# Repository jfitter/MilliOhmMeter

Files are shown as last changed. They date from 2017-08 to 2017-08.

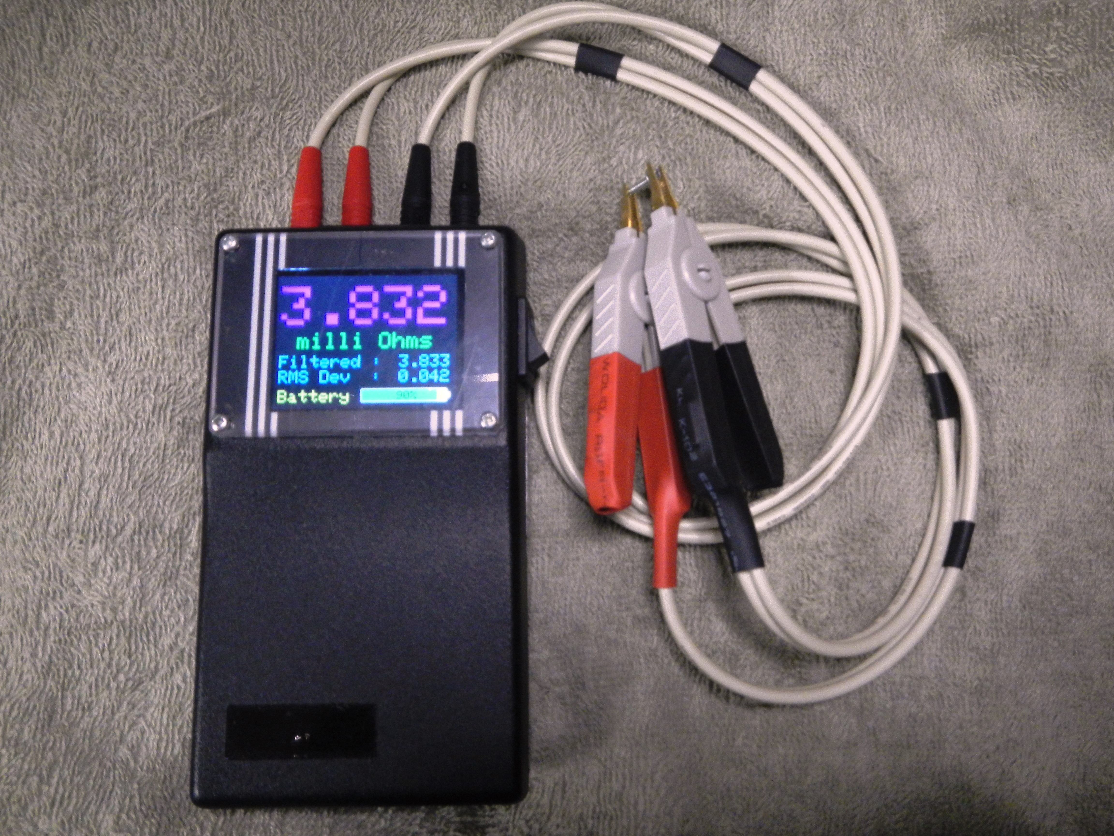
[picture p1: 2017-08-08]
Pictures/measure.jpg

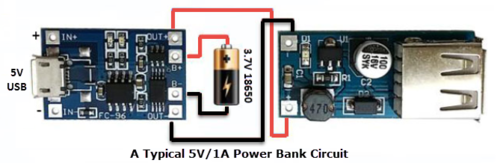
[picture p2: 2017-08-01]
Hardware/Micro-LI-Bat-Chg-Module-Connections.png

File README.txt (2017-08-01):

****************************************************************************************************
* This is the firmware for the MilliOhm Meter (described herein)                                   *
****************************************************************************************************

Firmware for MilliOhm Meter using the following hardware;
    Scullcom milliohm meter circuit
    Arduino Pro Mini
    ADS1115 breakout board
    2.2" 240x320 SPI TFT LCD with ILI9341 driver
    Micro USB single LiIon battery charger module
    LiIon single cell boost converter module
    18650 2500mAh LiIon cyclindrical cell

Hardware setup.
Using an Arduino Pro Mini @ 16MHz / 5V.

Description & Function              Arduino Arduino
======================              Pin #   Pin Name
                                    ======= ========
ADS1115 16b A/D Converter I2C
    SDA   (Serial Data)             A4      ADC4 (SDA)
    SCL   (Serial Clock)            A5      ADC5 (SCL)

2.2" TFT RGB 240x320 Display (ILI9341)
    MISO  (Serial Out)              12      PB4 (MISO) (Serial In)
    MOSI  (Serial In)               11      PB3 (MOSI) (Serial Out)
    SCK   (Serial Clock)            13      PB5 (SCK)  (Serial Clock)
    LED   (Backlight)               2       PD2
    DC/RS (SD Card Select)          3       PD3
    RST   (Reset)                   4       PD4
    CS    (LCD Select)              5       PD5

ADS1115 Module Analog Inputs
    0,1   Differential              MilliOhm meter output
    2     Single ended              LiIon battery voltage

Check that the archive contains the following files;

MilliOhmMeter.ino       Arduino C++ source
MilliOhmMeter.h         C++ header
MilliOhmMeter.chm       The HTML documentation
MilliOhmMeter.vcxproj   Visual Studio project file
Filter.h                Exponential Filter source
printf.h                Formatted print source
README.txt              This file
Doxyfile                Doxygen documentation configuration

MilliOhmMeter.chm contains the documentation for the firmware.

Written by John Fitter, Eagle Air Australia Pty. Ltd.
BSD license. All text above must be included in any redistribution

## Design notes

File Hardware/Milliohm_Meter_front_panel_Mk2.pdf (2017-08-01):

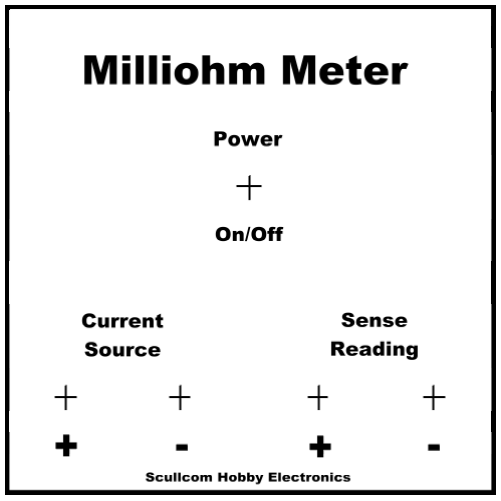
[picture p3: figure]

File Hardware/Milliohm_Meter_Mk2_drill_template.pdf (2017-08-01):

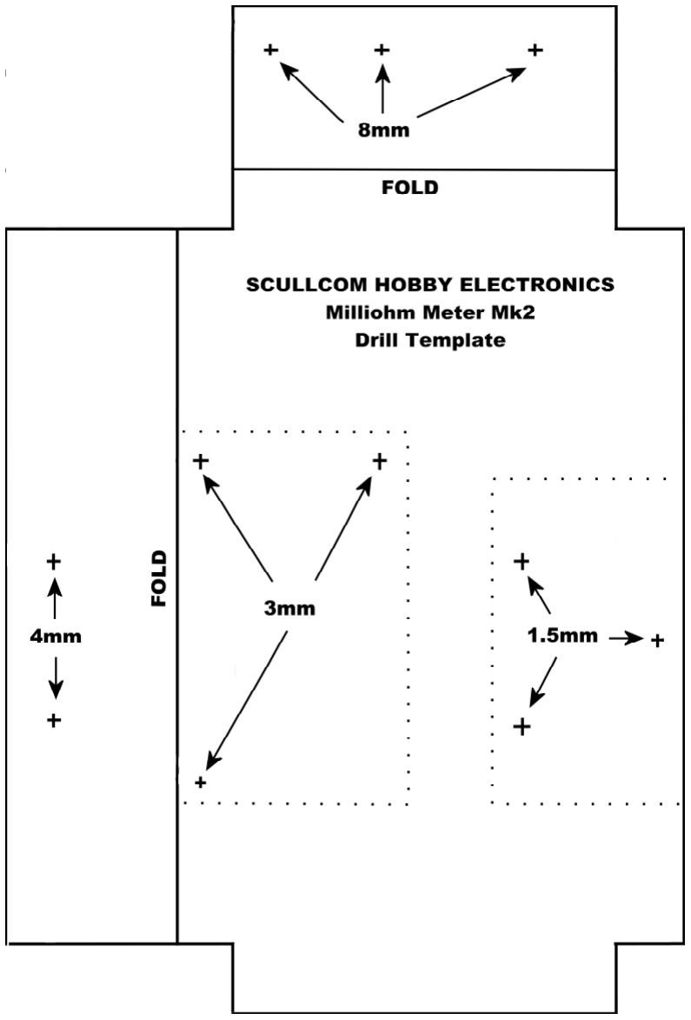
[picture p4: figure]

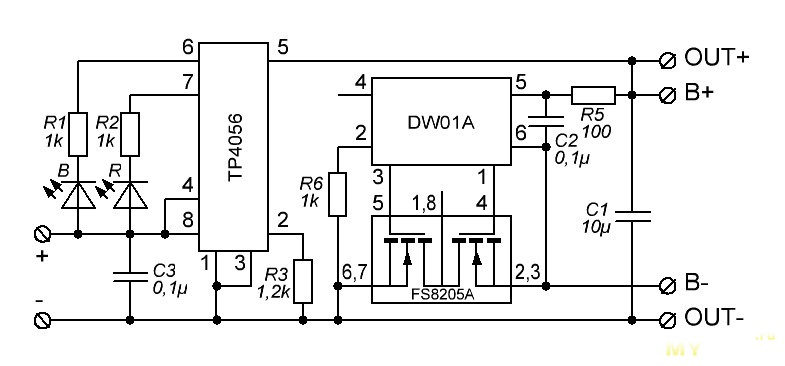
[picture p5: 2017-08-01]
Hardware/Micro-LI-Bat-Chg-Module-Schematic.jpg

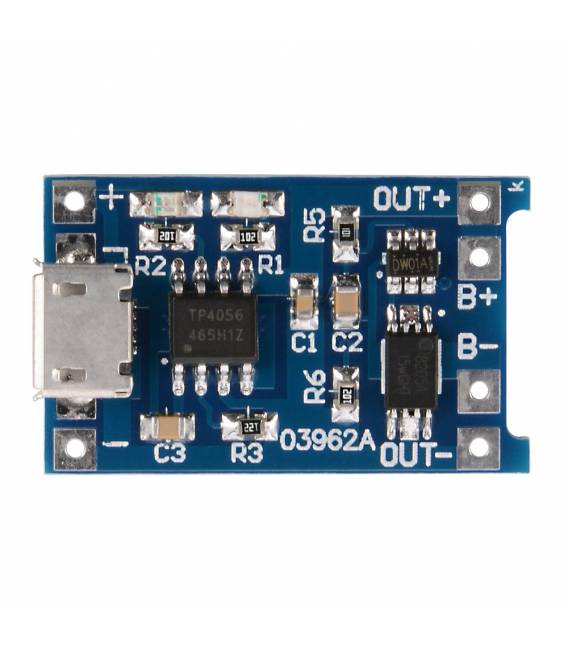
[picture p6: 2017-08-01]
Hardware/Micro-LI-Bat-Chg-Module-Image.jpg

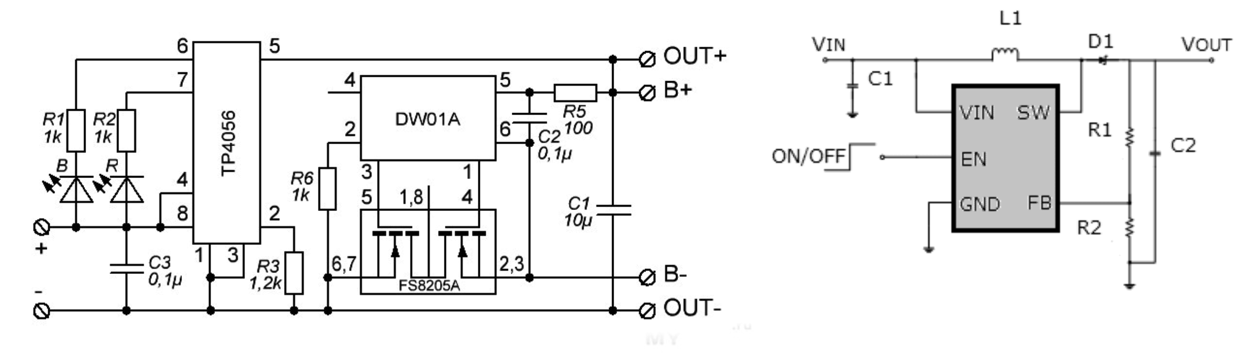
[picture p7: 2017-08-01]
Hardware/Power_Charging.jpg

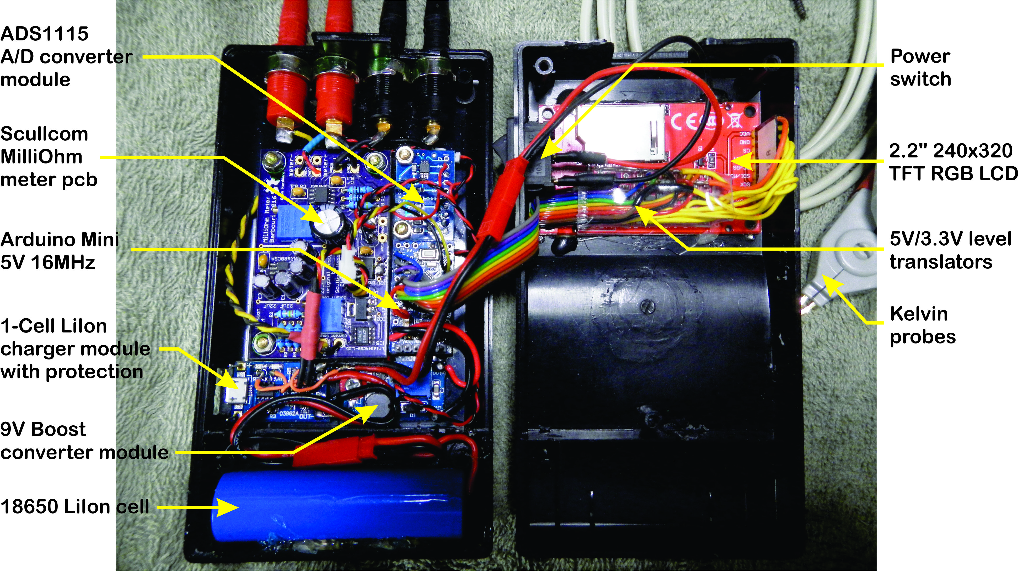
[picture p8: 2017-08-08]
Pictures/inside.jpg

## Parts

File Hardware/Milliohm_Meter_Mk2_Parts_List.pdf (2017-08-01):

SCULLCOM HOBBY ELECTRONICS - MILLIVOLT METER Mk2 PARTS LIST

PCB is available from OSH Park. A PCB (using surface mount components) designed by one of my subscribers “pbreviceps” (Greg Christenson). Greg has taken my design and produced a very high quality PCB (double sided) and made it freely available to purchase from OSH Park (3 blank PCB’s are supplied at a cost of US$19.5 plus shipping costs). Direct link: https://oshpark.com/shared_projects/UWvehNO2

1 x LM2940IMP-5.0 - SOT-223 (Farnell Order Code 1469076) 1 x LT3092EST#PBF - SOT223 (Farnell Order Code 2295469) 1 x LT1634BCS8-1.25#PBF NSOIC-8 (Farnell Order Code 1273451) 1 x MAX680CSA+ NSOIC-8 (Farnell Order Code 9725717) 1 x INA106U –SOIC (Farnell Order Code 1212395) 4 x 56.2 Ω 250 mW, ± 0.1% ±15ppm/°C (Farnell Order Code 9503277 or 1751304) 1 x 63.4 Ω 250 mW, ± 0.1% ±15ppm/°C (Farnell Order Code 1083123) 1 x 10 Ω 250 mW, ± 0.1% ±15ppm/°C (Farnell Order Code 1083036) 1 x 100 Ω 250 mW, ± 0.1% ±15ppm/°C (Farnell Order Code 9499865 or 1083143) 1 x 499 KΩ 250 mW, ± 0.1% ±15ppm/°C (Farnell Order Code 1083547) 1 x 220 μF 35v electrolytic (Farnell Order Code 1144628) or similar 4 x 22 μF 25v electrolytic (Farnell Order Code 2079085) or similar 5 x 0.1 μF ceramic (Farnell Order Code 2529480) or similar 1 x 100 Ω preset (BOURNS 3296P-1-101LF TRIMMER, 25 TURN 100R (Farnell Order Code 9353020)

1 x 100 KΩ preset (BOURNS 3296P-1-104LF TRIMMER, POT, 100K, 10%, 25TURN, (Farnell Order Code 9353054)

1 x 4 ½ Digit High Precision +/- 2V 0-1.9999V Red LED Digital Panel Meter.
From seller yourcartmax on eBay. Direct link below: http://www.ebay.co.uk/itm/261284812938?_trksid=p2057872.m2749.l2649&ssPageName=STRK%3AMEBID X%3AIT
or alternative from eBay seller coldfusionx, direct link: http://www.ebay.com/itm/350261421976

1 x Black textured ABS enclosure with sloping panel. 150mm length, 95mm width, height slopes from 33.2 to 49.5mm. From www.rapidonline.com (Order Code: 30-3606). Direct link below: https://www.rapidonline.com/rapid-g1168b-150x95x50-black-case-30-3606

1 x PP3 9V Battery Holder Clip Connector. From seller utronix_ltd on eBay. http://www.ebay.co.uk/itm/PP3-9V-BATTERY-HOLDER-CLIP-CONNECTOR-IDEAL-FOR-GUITAR-EFFECTS-PEDAL-/262341198335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

High quality Alligator Kelvin Test gold plated clip 2 Colors Red + Black. From seller louisliu2009 on eBay. Direct link below:
http://www.ebay.co.uk/itm/4pcs-High-quality-Alligator-Kelvin-Test-gold-plated-clip-2-Colors-Red-Black-/180779978390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

### 2 x 4mm Insulated Test Socket Red (Rapid order code 17-2677) or similar 2 x 4mm Insulated Test Socket Black (Rapid order code 17-2674) or similar 1 x 4mm Insulated Test Socket Yellow (Rapid order code 17-2679) or similar 1 x 4mm Insulated Test Socket Green (Rapid order code 17-2676) or similar

The 4mm sockets available from Rapid, direct link below: or similar https://www.rapidonline.com/4mm-insulated-test-socket-83057

### 1 x On/Off switch either toggle or push button

### 1 x 2.1mm pin diameter DC power socket (Rapid order code 50-3276) or similar

https://www.rapidonline.com/cliff-electronic-fc681445-dc-socket-5-5-x-2-1mm-model-scd-026-50-3276

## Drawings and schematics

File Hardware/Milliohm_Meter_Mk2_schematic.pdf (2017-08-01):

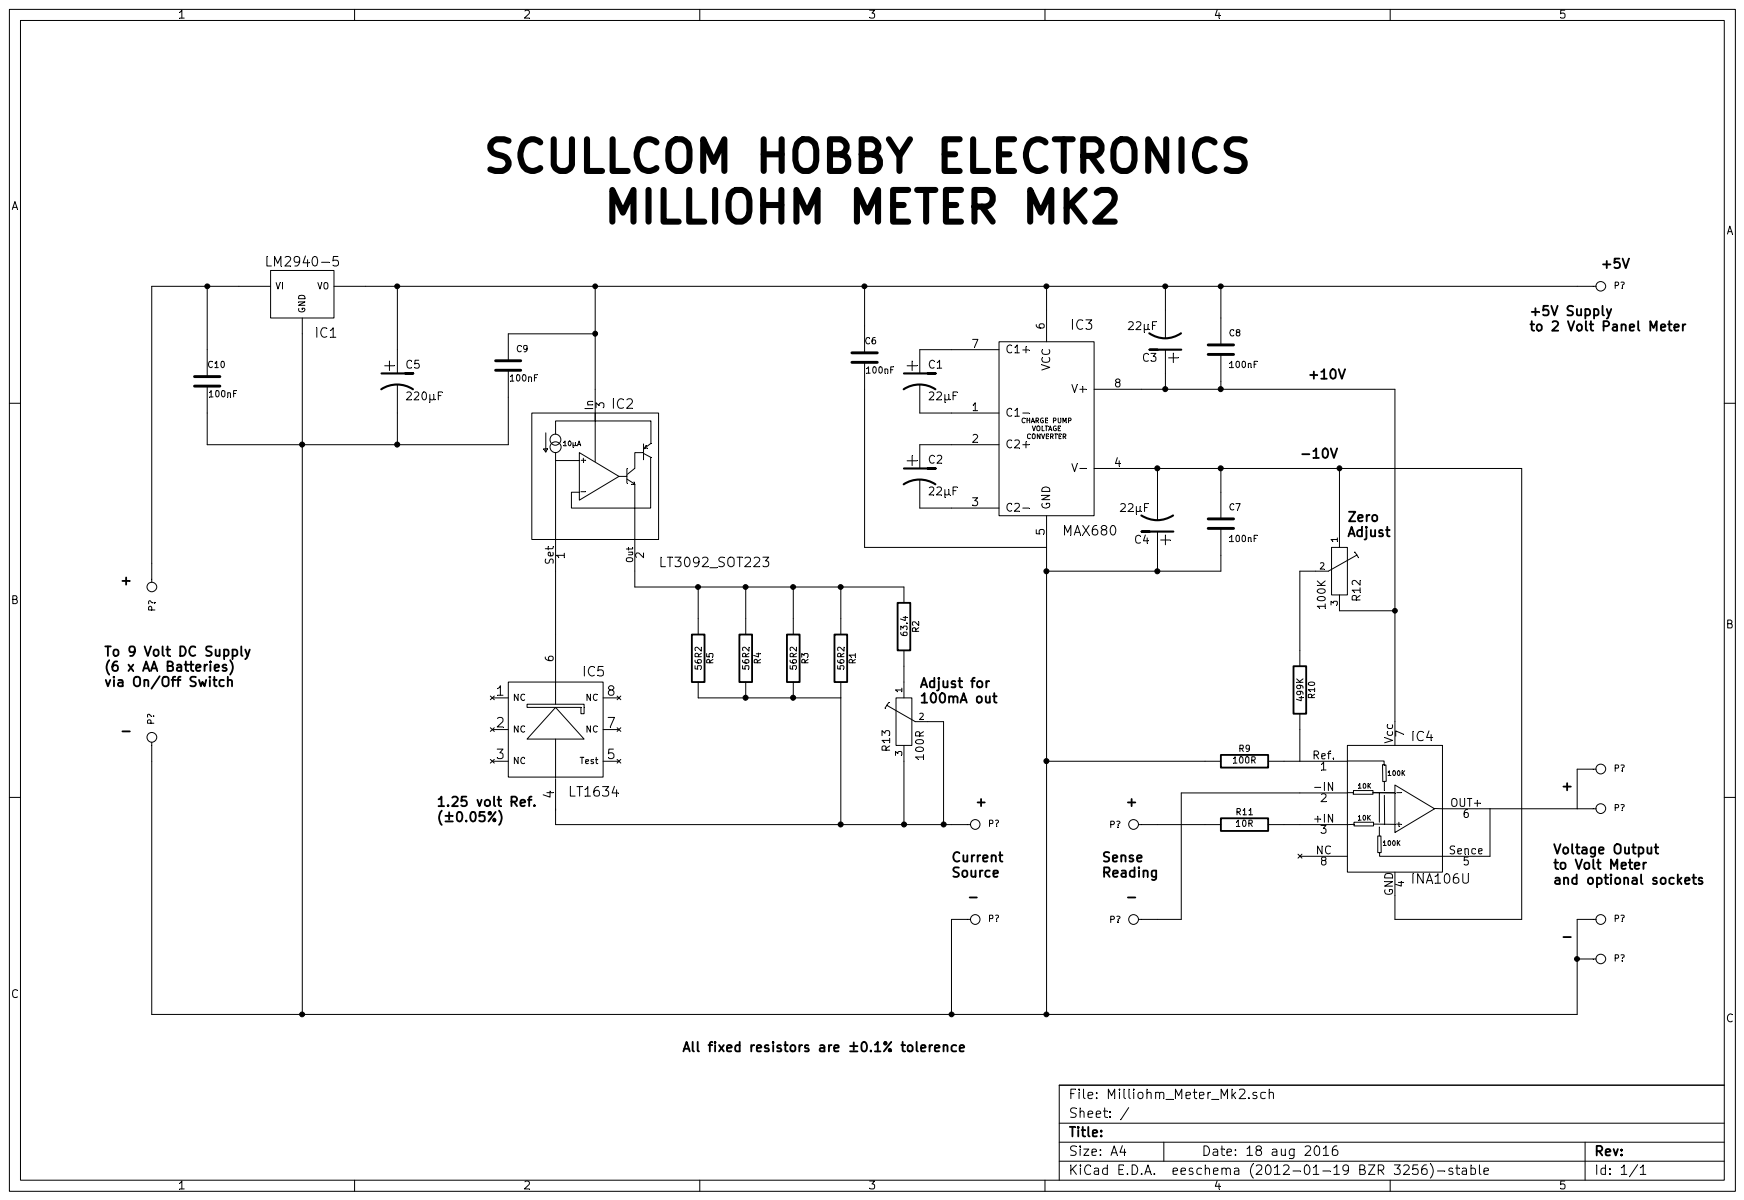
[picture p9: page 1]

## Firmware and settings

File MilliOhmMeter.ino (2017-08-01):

#define _MILLIOHMMETER_C
/***********************************************************************************************//**
 *  \par        MilliOhmMeter Control Program - Source File.
 *
 *  \par        Details
 *              Firmware for MilliOhm Meter using the following hardware;
 *  \li             Scullcom milliohm meter circuit
 *  \li             Arduino Pro Mini
 *  \li             ADS1115 breakout board
 *  \li             2.2" 240x320 SPI TFT LCD with ILI9341 driver
 *  \li             Micro USB single LiIon battery charger module
 *  \li             LiIon single cell boost converter module
 *  \li             18650 2500mAh LiIon cyclindrical cell
 *
 *  \file       MILLIOHMMETER.INO
 *  \author     J. F. Fitter <jfitter@eagleairaust.com.au>
 *  \version    1.0
 *  \date       July 2017
 *  \copyright  Copyright (c) 2017 John Fitter.  All right reserved.
 *
 *  \par        Changelog
 *              23jul2017  Initial release
 *
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
 *  \par
 *  \par        Hardware setup.
 *              Using an Arduino Pro Mini @ 16MHz / 5V.
 *  \verbatim
    Description & Function                     Arduino    Arduino
    ======================                     Pin #      Pin Name
                                               =======    ========
    ADS1115 16b A/D Converter I2C
        SDA   (Serial Data)                    A4         ADC4 (SDA)
        SCL   (Serial Clock)                   A5         ADC5 (SCL)

    2.2" TFT RGB 240x320 Display (ILI9341)
        MISO  (Serial Out)                     12         PB4 (MISO) (Serial In)
        MOSI  (Serial In)                      11         PB3 (MOSI) (Serial Out)
        SCK   (Serial Clock)                   13         PB5 (SCK)  (Serial Clock)
        LED   (Backlight)                      2          PD2
        DC/RS (SD Card Select)                 3          PD3
        RST   (Reset)                          4          PD4
        CS    (LCD Select)                     5          PD5

    ADS1115 Analog Inputs
        0,1   Differential                     MilliOhm meter output
        2     Single ended                     LiIon battery voltage
    \endverbatim
 *
 *//***********************************************************************************************/

#include <avr/pgmspace.h>
#include <Arduino.h>
#include <Wire.h>
#include <SPI.h>
#include <gfxfont.h>
#include <Adafruit_GFX.h>
#include <Adafruit_ILI9341.h>
#include <Adafruit_ADS1015.h>
#include <TimerUp.h>
#include "Filter.h"
#include "printf.h"

#include "MilliOhmMeter.h"

/**
 *  \brief    Program setup.
 *  \remarks  Performed once only at powerup.
 */
void setup() {

    #ifdef _DEBUG_
    startDebug();                                   // Start the debug output.
    #endif // _DEBUG_

    printf_begin();                                 // Start the printf formatter.
    Wire.begin();                                   // Start the serial bus.
    initBattery();                                  // Initialize battery monitoring hardware.
    initAds1115();                                  // Initialize ADS1115.
    initLcd();                                      // Initialize the LCD hardware.
}

/**
 *  \brief    Main program loop.
 *  \remarks  The main loop is merely a scheduler relying on the rollover of several timers to
 *            initiate functions.
 */
void loop() {
    if (procTimer[0].rollOver()) getResistance();
    if (procTimer[1].rollOver()) updateDisplay();
    if (procTimer[2].rollOver()) getBattVolts(); 
}

/**
 *  \brief                   Convert a double value to a formatted string.
 *  \remarks                 Unlike dtostrf() this procedure returns a string of only the specified
 *                           length, leading edge padded with spaces or truncated.
 *  \param [in] double val   Value to be converted.
 *  \param [in] uint8_t len  Length of the string to return.
 *  \param [in] uint8_t prec Precision (ie. number of decimals).
 *  \param [in] char *buf    String buffer to receive the result.
 *  \return     char*        Pointer to the formatted string buffer.
 */
char* dToStringFmt(double val, uint8_t len, uint8_t prec, char *buf) {
    uint8_t n = strlen(dtostrf(val, len, prec, buf));
    return &buf[n-len];
}

/**
 *  \brief    Update the values displayed on the LCD.
 *  \remarks  This procedure writes all of the variable data to the LCD. It performs
 *            Implement a simple linear recursive exponential filter. This is
 *            scaling of the value and selection of the appropriate units.
 */
void updateDisplay() {

    char buf[31];
    uint8_t dec = 0;
    double mul = 1000000.0;

    // If the resistance is over 5 then that is an overrange condition. Just say so and do nothing
    // else. This ensures that previous hard filtered values are held.
    if(resSFilter.Current() > 5.0) {
        writeLcdText("-----", LCD_XCENTER, LCD_YRES, LCD_RES_FONT_SIZE, 
            LCD_TXT_CENTER, LCD_RES_COLOR);
        writeLcdText("Over Range", LCD_XCENTER, LCD_YUNITS, LCD_UNITS_FONT_SIZE, 
            LCD_TXT_CENTER, LCD_UNITS_COLOR);
    } else {

        // Choose to display microOhms/milliOhms/Ohms, select a multiplier for the displayed value,
        // select decimal places, then write the units to the units line on the LCD.
        if(resSFilter.Current() < 0.001) {
            writeLcdText("micro Ohms", LCD_XCENTER, LCD_YUNITS, LCD_UNITS_FONT_SIZE, 
                LCD_TXT_CENTER, LCD_UNITS_COLOR);
        } else if(resSFilter.Current() < 1.0) {
            dec = resSFilter.Current() < 0.01 ? 3 : resSFilter.Current() < 0.1 ? 2 : 1; 
            mul = 1000.0;
            writeLcdText("milli Ohms", LCD_XCENTER, LCD_YUNITS, LCD_UNITS_FONT_SIZE, 
                LCD_TXT_CENTER, LCD_UNITS_COLOR);
        } else {
            dec = 3;
            mul = 1.0;
            writeLcdText("   Ohms   ", LCD_XCENTER, LCD_YUNITS, LCD_UNITS_FONT_SIZE, 
                LCD_TXT_CENTER, LCD_UNITS_COLOR);
        }
        // Write the soft filtered resistance value.
        writeLcdText(dToStringFmt(resSFilter.Current()*mul, 5, dec, buf), LCD_XCENTER, LCD_YRES, 
            LCD_RES_FONT_SIZE, LCD_TXT_CENTER, LCD_RES_COLOR);

        // Write the hard filtered resistance value and the square root of the summ of squares of 
        // the filtered value deviations. The RMS deviation is tested to be less than 10% of the 
        // filtered value. If not then neither the deviation nor the hard filtered values are 
        // displayed at all.
        if (sqrt(devFilter.Current()) > resHFilter.Current() / 10.0) {
            writeLcdText("-----", LCD_RIGHT, LCD_YLINE3, LCD_DATA_FONT_SIZE, 
                LCD_TXT_RIGHT, LCD_DATA_COLOR);
            writeLcdText("-----", LCD_RIGHT, LCD_YLINE4, LCD_DATA_FONT_SIZE, 
                LCD_TXT_RIGHT, LCD_DATA_COLOR);
        } else {
            writeLcdText(dToStringFmt(resHFilter.Current()*mul, 5, dec, buf), LCD_RIGHT,
                LCD_YLINE3, LCD_DATA_FONT_SIZE, LCD_TXT_RIGHT, LCD_DATA_COLOR);
            writeLcdText(dToStringFmt(sqrt(devFilter.Current())*mul, 5, dec, buf), LCD_RIGHT, 
                LCD_YLINE4, LCD_DATA_FONT_SIZE, LCD_TXT_RIGHT, LCD_DATA_COLOR);
        }
        // Just write the fixed text fields (in case they are corrupted for some reason).
        writeLcdText("Filtered :", LCD_LEFT, LCD_YLINE3, LCD_DATA_FONT_SIZE, LCD_TXT_LEFT, 
            LCD_DATA_COLOR);
        writeLcdText("RMS Dev  :", LCD_LEFT, LCD_YLINE4, LCD_DATA_FONT_SIZE, LCD_TXT_LEFT, 
            LCD_DATA_COLOR);
    }
    #ifdef _DEBUG_
    Serial.print(F("Gain: "));
    switch (gn) {
        case GAIN_SIXTEEN   : Serial.print(F("16 ")); break;
        case GAIN_EIGHT     : Serial.print(F("8  ")); break;
        case GAIN_FOUR      : Serial.print(F("4  ")); break; 
        case GAIN_TWO       : Serial.print(F("2  ")); break;   
        case GAIN_ONE       : Serial.print(F("1  ")); break;    
        default             : Serial.print(F("2/3"));
    }
    sprintf_P(buf, PSTR(" Raw: %5d %5d "), rw, rawFilter.Current());
    Serial.print(buf);
    Serial.print(F(" Res: "));
    Serial.print(dtostrf(resSFilter.Current(), 8, 6, buf));
    Serial.print(F("R  Bat: "));
    Serial.print(dtostrf(dblBatV, 5, 3, buf));
    Serial.print(F("V  Status: "));
    if(!digitalRead(CHG_PIN))  Serial.print(F("Chg"));
    if(!digitalRead(STBY_PIN)) Serial.print(F("|Stby"));
    Serial.println();
    #endif // _DEBUG_
}

/**
 *  \brief      Draw the battery charge status indicator.
 *  \remarks    Draws an indicator bar on the LCD showing the amount of charge remaining in the 
 *              battery and overlain by the battery state in text. If the battery is charging
 *              then a charging symbol is shown.
 *  \param [in] uint8_t  charge  The charge level of the battery in 1/2% increments (0..200).
 *  \param [in] BatState status  The charge status of the battery.
 */
void drawBatteryStatus(uint8_t charge, BatState status) {

    char buf[18]; // Keep this updated with code changes.

    // Draw the bar indicator. It shows percentage charge in 1/2 % increments.
     uint8_t midX = (BAT_BAR_LENGTH * (uint16_t)charge) / 200;

    Lcd.fillRect(BAT_BAR_LEFT, BAT_BAR_TOP, midX, BAT_BAR_HEIGHT, status == BAT_EMPTY ? 
        BAT_BAR_COLOR_LOW : BAT_BAR_COLOR_FG);
    Lcd.fillRect(BAT_BAR_LEFT+midX, BAT_BAR_TOP, BAT_BAR_LENGTH-midX, BAT_BAR_HEIGHT, 
        BAT_BAR_COLOR_BKG);
    Lcd.fillRoundRect(BAT_IND_LEFT+BAT_IND_LENGTH-2, BAT_IND_TOP+(BAT_IND_HEIGHT-BAT_IND_TERMH)/2,
        BAT_IND_TERML+2, BAT_IND_TERMH, 2, BAT_BAR_COLOR_BDR);
    Lcd.drawRoundRect(BAT_IND_LEFT, BAT_IND_TOP, BAT_IND_LENGTH, BAT_IND_HEIGHT, 3, 
        BAT_BAR_COLOR_BDR);
    Lcd.drawRoundRect(BAT_IND_LEFT+1, BAT_IND_TOP+1, BAT_IND_LENGTH-2, BAT_IND_HEIGHT-2, 2, 
        BAT_BAR_COLOR_BDR);

    // Write the battery status text information.
    switch (status) {
        case BAT_EMPTY : // Battery is empty.
            writeLcdText("DISCHARGED", BAT_BAR_MIDX, LCD_YLINE_BAR, LCD_BAR_FONT_SIZE, 
                LCD_TXT_CENTER, ILI9341_BLACK, true);
            break;
        case BAT_CHARGING : // Battery is charging so draw a shocko symbol on the bar indicator.
            Lcd.fillTriangle(BAT_BAR_MIDX+SHOCKO_HEIGHT/10, BAT_BAR_MIDY-SHOCKO_HEIGHT/2, 
                             BAT_BAR_MIDX+SHOCKO_HEIGHT/10, BAT_BAR_MIDY+SHOCKO_HEIGHT/10, 
                             BAT_BAR_MIDX-SHOCKO_HEIGHT,    BAT_BAR_MIDY+SHOCKO_HEIGHT/5, 
                             BAT_SHOCKO_COLOR);
            Lcd.fillTriangle(BAT_BAR_MIDX-SHOCKO_HEIGHT/10, BAT_BAR_MIDY+SHOCKO_HEIGHT/2, 
                             BAT_BAR_MIDX-SHOCKO_HEIGHT/10, BAT_BAR_MIDY-SHOCKO_HEIGHT/10, 
                             BAT_BAR_MIDX+SHOCKO_HEIGHT,    BAT_BAR_MIDY-SHOCKO_HEIGHT/5, 
                             BAT_SHOCKO_COLOR);
            break;
        case BAT_FULL : // Battery is full.
            writeLcdText("CHARGED", BAT_BAR_MIDX, LCD_YLINE_BAR, LCD_BAR_FONT_SIZE, 
                LCD_TXT_CENTER, ILI9341_BLACK, true);
            break;        
        case BAT_NONE : // None or disconnected battery.
            writeLcdText("NO BATTERY", BAT_BAR_MIDX, LCD_YLINE_BAR, LCD_BAR_FONT_SIZE, 
                LCD_TXT_CENTER, ILI9341_BLACK, true);
            break;        
        default : // All is normal so just write the battery charge percentage.
            sprintf_P(buf, PSTR("%3u%%"), charge/2); 
            writeLcdText(buf, BAT_BAR_MIDX, LCD_YLINE_BAR, LCD_BAR_FONT_SIZE, 
                LCD_TXT_CENTER, ILI9341_BLACK, true);
    }
    writeLcdText("Battery", LCD_LEFT, LCD_YLINE_BAT, LCD_BAT_FONT_SIZE, 
        LCD_TXT_LEFT, LCD_MSG_COLOR);
}

/**
 *  \brief    Get the resistance value.
 *  \remarks  Reads the A/D converter to get raw data then converts it to a resistance. The 
 *            resistance value is filtered with a digital filter and the difference between the 
 *            computed resistance and the filtered resistance is squared and filtered. The filters
 *            implement simple linear recursive exponential filters. These are essentially first
 *            order FIR filters which are ideal for the removal of white noise typically found on
 *            sensor data. They are not suitable for spectral filtering.
 *  \par      
 *            The meter circuit provides 100mA of source current so the resistance
 *            is equal to Measured Voltage * 10 where Measured Voltage is the raw a/d value
 *            multiplied by a gain factor in V/bit.
 *  \par      
 *            The raw a/d value is compared to the hysteresis limit for the purpose of changing
 *            the gain of the PGA. If the raw value is below the lower limit then the gain is
 *            increased. If the value is above the upper limit then the gain is reduced. The
 *            hysteresis is necessary to prevent the display from flickering between ranges.
 */
void getResistance() {

    // Get the raw integer value of the a/d converter. Valide range is 0..0x7FFF
    int16_t raw = Ads1115.readADC_SingleEnded(0);

    #ifdef _DEBUG_
    rawFilter.Filter(raw);
    rw = raw;
    gn = Ads1115.getGain();
    #endif // _DEBUG_

    // Just throw away negative voltages.
    if(raw < 0) raw = 0;

    // Use this value to update the resistance and deviation filter.
    // adjustGain() returns Ohms/bit.
    double res = adjustGain(DIR_AS) * raw;
    resSFilter.Filter(res);
    resHFilter.Filter(res);
    devFilter.Filter(sqr(res-resHFilter.Current()));   

    // Change the gain settings for next loop based on specified hysteresis limits.
    if (raw < RAW_ADS_SPAN/2-RAW_HYSTERESIS) adjustGain(DIR_UP);
    else if(raw > RAW_ADS_SPAN/2+RAW_HYSTERESIS) adjustGain(DIR_DN);                  
}                                                                           

/**
 *  \brief                  Change the gain of the A/D converter PGA.
 *  \remarks                Changes the gain by one step only, either up, down, or no change.
 *  \param [in] Direction_t dir   Direction to adjust the gain.
 *  \return     double      gain factor (Ohms/bit).
 */
double adjustGain(Direction_t dir) {

    adsGain_t gain = Ads1115.getGain();

    if(dir != DIR_AS)  {
        switch (gain) {
            case GAIN_SIXTEEN   : gain = dir == DIR_UP ? GAIN_SIXTEEN : GAIN_EIGHT;     break;
            case GAIN_EIGHT     : gain = dir == DIR_UP ? GAIN_SIXTEEN : GAIN_FOUR;      break;
            case GAIN_FOUR      : gain = dir == DIR_UP ? GAIN_EIGHT   : GAIN_TWO;       break;
            case GAIN_TWO       : gain = dir == DIR_UP ? GAIN_FOUR    : GAIN_ONE;       break;
            case GAIN_ONE       : gain = dir == DIR_UP ? GAIN_TWO     : GAIN_TWOTHIRDS; break;
            default             : gain = dir == DIR_UP ? GAIN_ONE     : GAIN_TWOTHIRDS;
        }
        Ads1115.setGain(gain);
    }
    // Return the gain in Ohms/bit.
    switch (gain) {
        case GAIN_SIXTEEN   : return VPB_SIXTEEN / RES_TEST_CURRENT / DIFF_AMP_GAIN;
        case GAIN_EIGHT     : return VPB_EIGHT   / RES_TEST_CURRENT / DIFF_AMP_GAIN; 
        case GAIN_FOUR      : return VPB_FOUR    / RES_TEST_CURRENT / DIFF_AMP_GAIN;  
        case GAIN_TWO       : return VPB_TWO     / RES_TEST_CURRENT / DIFF_AMP_GAIN;   
        case GAIN_ONE       : return VPB_ONE     / RES_TEST_CURRENT / DIFF_AMP_GAIN;    
    }
    return VPB_TWOTHIRDS / RES_TEST_CURRENT / DIFF_AMP_GAIN;   // default is GAIN_TWOTHIRDS
}

/**
 *  \brief    Initialize the battery monitoring hardware.
 *  \remarks  This is just 2 pins to monitor the status of the TP4056 status pins. These pins
 *            are open drain and drive 2 on-board LEDs connected to USB power. The CPU can monitor
 *            them through a series diode thereby preventing the CPU pins from being energised
 *            by the charger when the CPU power is removed (switch off).
 */
void initBattery() {

    pinMode(CHG_PIN,  INPUT_PULLUP);
    pinMode(STBY_PIN, INPUT_PULLUP);
}

/**
 *  \brief    Get the battery voltage.
 *  \remarks  The battery is a single LiIon cylindrical cell. It is nominally 3.7V and 4.2V at 
 *            full charge. It is 2.4V fully discharged. The voltage is measured single ended 
 *            (ie. referenced to ground) and the gain is set for a 6.144V range. On completion
 *            the gain is restored to its previous value.
 */
void getBattVolts() {

    // Save the A/D converter gain.
    adsGain_t gain = Ads1115.getGain();
    Ads1115.setGain(GAIN_TWOTHIRDS);

    // Get the battery voltage using the lowest A/D converter gain..
    dblBatV = VPB_TWOTHIRDS * Ads1115.readADC_SingleEnded(2);

    // Restore the A/D converter gain.
    Ads1115.setGain(gain);

    // Convert the battery voltage to a state of charge (0 to 200, 0.5% increments).
    uint8_t chgVal = dblBatV < BAT_VDISCHARGED ? 0 : dblBatV >= BAT_VCHARGED ? 200 :
        (uint8_t)((dblBatV-BAT_VDISCHARGED)/(BAT_VCHARGED-BAT_VDISCHARGED)*200.0);

    // Get the battery operating status from the status pins.
    bool chg  = !digitalRead(CHG_PIN);
    bool stby = !digitalRead(STBY_PIN);

    // Convert the operating status to a battery state.
    BatState chgState;   
    if(chg && !stby) chgState = BAT_CHARGING;
    else if((chgVal < 200) && (chgVal > 0)) chgState = BAT_NORMAL;
    else if (!chg && stby && (chgVal >= 200)) chgState = BAT_FULL;
    else if (!chg && !stby) chgState = BAT_NONE;
    else chgState = BAT_EMPTY;

    // Now draw the battery indicator showing battery state and voltage.
    drawBatteryStatus(chgVal, chgState);   
}

/**
 *  \brief    Initialize the ADS1115 16b A/D converter.
 *  \remarks  Starts the converter and sets the converter to the default gain.
 */
void initAds1115() {
    Ads1115.begin();                                // Initialize ADS1115
    Ads1115.setGain(GAIN_TWOTHIRDS);                // +/- 6.144V 187.5uV/bit
}

/**
 *  \brief                 Writes a text string to the LCD.
 *  \remarks               Generic text string writer. Draws the text clear.
 *  \param [in] char*      buf      Buffer containing the string.
 *  \param [in] int16_t    x        X position of the string reference in pixels.
 *  \param [in] int16_t    y        Y position of the string reference in pixels.
 *  \param [in] uint8_t    size     Text size.
 *  \param [in] LcdTxtJust just     Location of the string reference.
 *  \param [in] uint16_t   fgcolor  Color of the text.
 */
void writeLcdText(char *buf, int16_t x, int16_t y, uint8_t size, 
    LcdTxtJust just, uint16_t fgcolor, boolean clear) {
    switch (just) {
        case LCD_TXT_LEFT:   Lcd.setCursor(x, y); break;
        case LCD_TXT_CENTER: Lcd.setCursor(x - strlen(buf) * 3 * size, y); break;
        case LCD_TXT_RIGHT:  Lcd.setCursor(x - strlen(buf) * 6 * size, y);
    }
    Lcd.setTextSize(size);
    if(clear) Lcd.setTextColor(fgcolor);
    else Lcd.setTextColor(fgcolor, LCD_BK_COLOR);
    Lcd.print(buf);
}

/**
*  \brief    Initialize the LCD.
*  \remarks  Sets up the LCD orientation, background color, text color, text wrap and mode.
*  \li       Initializes the backlight PWM modulator.
*  \li       Writes the splash screen, pauses, then fills the screen with the background color.
*/
void initLcd() {

    // Setup the LCd.
    Lcd.begin();
    Lcd.setRotation(3);
    Lcd.fillScreen(LCD_BK_COLOR);
    Lcd.setTextWrap(false);

    // Setup the backlight. This is PWM and may be under user control in a future version.
    pinMode(LCD_BL_PIN, OUTPUT);
    analogWrite(LCD_BL_PIN, (LCD_DEF_BL_LEVEL * 128) / 100);

    // Write the splash screen.
    Lcd.setTextSize(2);
    Lcd.setTextColor(LCD_MSG_COLOR);
    Lcd.setCursor(LCD_LEFT, LCD_TB_MARGIN + 10);
    writeLcdText(xstr(_DEVICENAME_), LCD_LEFT, LCD_TB_MARGIN + 10, 3, LCD_TXT_LEFT, LCD_RES_COLOR);
    writeLcdText(xstr(_PROGNAME_), LCD_LEFT, LCD_TB_MARGIN + 40, 3, LCD_TXT_LEFT, LCD_RES_COLOR);
    writeLcdText("Version " xstr(_VERSION_MAJOR_) "." xstr(_VERSION_MINOR_) "." xstr(_REVISION_)
         " " xstr(_DATE_), LCD_LEFT, LCD_TB_MARGIN + 90, 2, LCD_TXT_LEFT, LCD_DATA_COLOR);
    writeLcdText("Author : " xstr(_AUTHOR_), LCD_LEFT, LCD_TB_MARGIN + 130, 2, 
         LCD_TXT_LEFT, LCD_UNITS_COLOR);
    writeLcdText("Copyright (c) " xstr(_COPYRIGHT_), LCD_LEFT, LCD_TB_MARGIN + 155, 2,
         LCD_TXT_LEFT, LCD_MSG_COLOR);
    writeLcdText(xstr(_COMPANY_), LCD_LEFT, LCD_TB_MARGIN + 180, 2, LCD_TXT_LEFT, LCD_MSG_COLOR);
    writeLcdText("All rights reserved", LCD_LEFT, LCD_TB_MARGIN + 205, 2,
         LCD_TXT_LEFT, LCD_MSG_COLOR);

    // Wait a while then clear the display.
    delay(LCD_SPLASH_DELAY);
    Lcd.fillScreen(LCD_BK_COLOR);
}

#ifdef _DEBUG_
/**
*  \brief    Start a debugging session.
*  \remarks  Sets the serial monitor baud rate and writes a header to the monitor.
*/
void startDebug() {
    Serial.begin(BAUDRATE);
    Serial.println(F("\r\nMilliOhmMeter Control Program"));
    Serial.println(F("Author: J. F. Fitter"));
    Serial.println(F("Copyright c 2017 All rights reserved.\r\n"));
}

#endif // _DEBUG_


// EOF MILLIOHMMETER.INO

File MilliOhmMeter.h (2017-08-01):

#ifndef _MILLIOHMMETER_H
#define _MILLIOHMMETER_H
/***********************************************************************************************//**
 *  \par        MilliOhmMeter Control Program - Header File.
 *  \file       MILLIOHMMETER.H
 *  \author     J. F. Fitter <jfitter@eagleairaust.com.au>
 *  \version    1.0
 *  \date       July 2017
 *  \copyright  Copyright (c) 2017 John Fitter.  All right reserved.
 *
 *  \par        Changelog
 *              23jul2017  Initial release
 *
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
 *//***********************************************************************************************/

//#define _DEBUG_
#define __STDC_LIMIT_MACROS
#define __STDC_CONSTANT_MACROS


#define _DEVICENAME_        MilliOhm Meter        
#define _PROGNAME_          Control Firmware      
#define _AUTHOR_            J.F.Fitter  
#define _VERSION_MAJOR_     1
#define _VERSION_MINOR_     0
#define _REVISION_          0
#define _DATE_              25jul2017
#define _COPYRIGHT_         2017      
#define _COMPANY_           Eagle Air Australia p/l

// Usefull macros.
#define str(s)              #s
#define xstr(s)             str(s)
#define sqr(x)              ((x)*(x))

// Communications definitions.
#define BAUDRATE            115200                      /**< Serial comms data bit rate (bps)*/

// Hardware definitions.
#define CHG_PIN             6                           /**< Charging status pin */
#define STBY_PIN            7                           /**< Standby status pin */
#define LCD_BL_PIN          3                           /**< LCD backlight pin */
#define LCD_DC_PIN          2                           /**< SD card select pin ?????? */
#define LCD_RST_PIN         4                           /**< LCD reset pin */
#define LCD_CS_PIN          5                           /**< LCD selsect pin */
#define RES_TEST_CURRENT    0.1                         /**< Resistance test current (A) */
#define DIFF_AMP_GAIN       10.0                        /**< Differential amplifier gain */

// Data filtering definitions.
#define FILTERWT_RESS       80                          /**< Resistance soft filter strength (100 = min) */
#define FILTERWT_RESH       10                          /**< Resistance hard filter strength */
#define FILTERWT_DEV        10                          /**< Deviation filter strength */

// Sample and display rate definitions.
#define RES_SAMPLE_RATE     50                          /**< Resistance sample rate (sps) */
#define BAT_SAMPLE_RATE     1                           /**< Battery voltage sample rate (sps) */
#define LCD_REFRESH_RATE    3                           /**< LCD frame refresh rate (fps) */

// LCD geometry definitions.
#define LCD_WIDTH           320                         /**< LCD width in pixels */
#define LCD_HEIGHT          240                         /**< LCD height in pixels */
#define LCD_LR_MARGIN       10                          /**< LCD Screen left/right margins */
#define LCD_TB_MARGIN       10                          /**< LCD Screen top/bottom margins */

#define LCD_LEFT            LCD_LR_MARGIN
#define LCD_RIGHT           (LCD_WIDTH-LCD_LR_MARGIN)
#define LCD_TOP             LCD_TB_MARGIN
#define LCD_BOTTOM          (LCD_HEIGHT-LCD_TB_MARGIN)
#define LCD_XCENTER         ((LCD_LEFT+LCD_RIGHT)/2)
#define LCD_YCENTER         ((LCD_TOP+LCD_BOTTOM)/2)

// LCD management definitions.
#define LCD_DEF_BL_LEVEL    60                          /**< Backlight intensity % */
#define LCD_SPLASH_DELAY    2000                        /**< Splash screen display time ms */

// Autoranging definitions.
#define RAW_ADS_SPAN        0x8000                      /**< Span of A/D converter single ended */ 
#define RAW_HYSTERESIS      0x1000                      /**< Raw data hysteresis */

// A/D Converter range factors in V/bit.
#define VPB_SIXTEEN        0.0000078125                 /**< A/D gain 16x range factor V/bit */
#define VPB_EIGHT          0.000015625                  /**< A/D gain 8x range factor V/bit */
#define VPB_FOUR           0.00003125                   /**< A/D gain 4x range factor V/bit */
#define VPB_TWO            0.0000625                    /**< A/D gain 2x range factor V/bit */
#define VPB_ONE            0.000125                     /**< A/D gain 1x range factor V/bit */
#define VPB_TWOTHIRDS      0.0001875                    /**< A/D gain 2/3x range factor V/bit */

// LCD color definitions.
#define LCD_BK_COLOR        ILI9341_BLACK               /**< LCD background color */
#define LCD_RES_COLOR       ILI9341_MAGENTA             /**< LCD color of resistance value */
#define LCD_UNITS_COLOR     ILI9341_GREEN               /**< LCD color of resistance units */
#define LCD_MSG_COLOR       ILI9341_YELLOW              /**< LCD color of messages */
#define LCD_DATA_COLOR      ILI9341_CYAN                /**< LCD color of additional data */

// LCD data layout definitions.
#define LCD_RES_FONT_SIZE   10                          /**< Resistance font size */
#define LCD_YRES            (LCD_TOP+10)                /**< Resistance line Y-position */  

#define LCD_UNITS_FONT_SIZE 4                           /**< Units font size */
#define LCD_YUNITS          (LCD_YRES+9*LCD_RES_FONT_SIZE-5) /**< Units line Y-position */    

#define LCD_DATA_FONT_SIZE  3                           /**< Data font size */
#define LCD_YLINE3          (LCD_YUNITS+9*LCD_UNITS_FONT_SIZE+5) /**< Data line 1 Y-position */ 
#define LCD_YLINE4          (LCD_YLINE3+9*LCD_DATA_FONT_SIZE)  /**< Data line 1 Y-position */ 

// Battery management definitions.
#define BAT_VMINOP          3.0                         /**< Battery min operating voltage (V) */
#define BAT_VCHARGED        4.2                         /**< Battery fully charged voltage (V) */
#define BAT_VDISCHARGED     2.4                         /**< Battery discharged voltage (V) */

#define LCD_BAT_FONT_SIZE   3                           /**< Battery data font size */
#define LCD_BAR_FONT_SIZE   2                           /**< Battery status indicator text font size */
#define BAT_IND_TERML       5                           /**< Battery status indicator terminal length */
#define BAT_IND_TERMH       10                          /**< Battery status indicator terminal height */

#define BAT_IND_HEIGHT      24                          /**< Battery status indicator height */
#define BAT_IND_LENGTH      (LCD_RIGHT-LCD_LEFT-8*6*LCD_BAT_FONT_SIZE-BAT_IND_TERML) /**< Battery status indicator length */
#define BAT_IND_LEFT        (LCD_RIGHT-BAT_IND_LENGTH-BAT_IND_TERML)  /**< Battery status indicator left */
#define BAT_IND_TOP         (LCD_BOTTOM-BAT_IND_HEIGHT) /**< Battery status indicator top */

#define BAT_BAR_HEIGHT      (BAT_IND_HEIGHT-4)
#define BAT_BAR_LENGTH      (BAT_IND_LENGTH-4)
#define BAT_BAR_LEFT        (BAT_IND_LEFT+2)
#define BAT_BAR_TOP         (BAT_IND_TOP+2)

#define BAT_BAR_MIDX        (BAT_BAR_LEFT+BAT_BAR_LENGTH/2)
#define BAT_BAR_MIDY        (BAT_BAR_TOP+BAT_BAR_HEIGHT/2)
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

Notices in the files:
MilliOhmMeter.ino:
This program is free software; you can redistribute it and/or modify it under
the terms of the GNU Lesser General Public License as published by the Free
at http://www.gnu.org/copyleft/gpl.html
